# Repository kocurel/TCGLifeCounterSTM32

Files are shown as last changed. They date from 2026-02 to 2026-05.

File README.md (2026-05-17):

# STATUS: **WIP**

## Project: [TCGLifeCounterSTM32]
> Based on the predecessor: **TCGLifeCounterESP32**

## Project Overview
An advanced life counter for Trading Card Games (TCG), serving as an evolution of the TCG Life Counter model. The main focus is on mechanical and electronic optimization, specifically targeting miniaturization (component height limit H < 3mm) and UI tactile improvements.

## Versioning
- **v0.0.5**: Power delivery changes, schematic cleanup, LCD pin labeling, switching to a 100-pin STM32
- **v0.0.4**: Minor fix
- **v0.0.3**: MCU power delivery circuit
- **v0.0.2**: Backlight power circuit
- **v0.0.1**: Initial Draft

## Hardware Architecture & Design Decisions

### 1. Power Management (Backlight)
LCD backlight power delivery is based on the **AP3012** step-up converter in a **Constant Current** configuration:
- **Current Stabilization**: Implemented Low-Side Sensing with an **82 Ohm** sense resistor, forcing a stable **15.24 mA** current for the LEDs.
- **Brightness Control**: Managed via the **SHDN** pin using a PWM signal.

### 2. UI & Mechanicals
- **Tactile Switches**: Switched to **Omron B3F-4050** (130gf) to reduce noise and improve actuation ergonomics.
- **Stack-up**: Maximum component height under the display is **1.5 mm**, ensuring a safe clearance margin within the 3 mm profile.

## Project Structure
- `/hardware` - KiCad 9.0 project files (Schematics, PCB, Libraries).
- `/docs` - Technical documentation and comparative analyses:
    - `backlight_analysis.txt` - Detailed analysis of the FB loop and capacitor selection.
    - `switch_analysis.txt` - Comparison of switch acoustic parameters.
- `/firmware` - MCU source code (C/C++).

## Getting Started
### Prerequisites
- **KiCad 9.0+** (Required to open the latest `.kicad_pro` files).

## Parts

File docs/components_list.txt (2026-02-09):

https://www.tme.eu/pl/details/smd0805-82r-1%25/rezystory-smd/royalohm/0805s8f820jt5e/
https://www.tme.eu/pl/details/stm32h562rgt6/mikrokontrolery-st/stmicroelectronics/
https://www.tme.eu/en/details/ap3012ktr-e1/voltage-regulators-dc-dc-circuits/diodes-incorporated/
https://www.tme.eu/pl/details/vls3012cx-100m-1/dlawiki/tdk/
https://www.tme.eu/en/details/dt024dtft/tft-displays/displaytech/
https://www.tme.eu/en/details/cl21b105kbfnnne/mlcc-smd-capacitors/samsung/
https://www.tme.eu/pl/en/details/zl322-2x7p/pin-headers/connfly/ds1031-08-2-7p8bs41-3a/
https://www.tme.eu/en/details/usb4105-gf-a-120/usb-ieee1394-connectors/gct/
https://www.tme.eu/pl/details/esda25sc6y/diody-tvs-smd-jednokierunkowe/stmicroelectronics/
https://www.tme.eu/pl/details/cl10a106kp8nnnc/kondensatory-mlcc-smd/samsung/
https://www.tme.eu/pl/details/mcp73831t-2ati_ot/kontrolery-baterii-i-akumulatorow-uklady/microchip-technology/
https://www.tme.eu/pl/details/plp2-375/swiatlowody-do-led/bivar/
https://www.tme.eu/pl/details/ltst-c191krkt/diody-led-smd-kolorowe/liteon/
https://www.tme.eu/pl/details/cl10a475kp8nnnc/kondensatory-mlcc-smd/samsung/
https://www.tme.eu/pl/details/ap2112k-3.3trg1/stabilizatory-napiecia-nieregulowane-ldo/diodes-incorporated/
https://www.tme.eu/pl/details/c0603c104k8rac/kondensatory-mlcc-smd/kemet/c0603c104k8ractu/
https://www.tme.eu/pl/details/cl10b105ko8nnnc/kondensatory-mlcc-smd/samsung/
https://www.tme.eu/pl/details/grm188z71c475ke21d/kondensatory-mlcc-smd/murata/
https://www.tme.eu/pl/details/cl21b106koqnnne/kondensatory-mlcc-smd/samsung/
https://www.tme.eu/pl/details/grm188r61e106ka73d/kondensatory-mlcc-smd/murata/
https://www.tme.eu/pl/details/06033d104kat2a/kondensatory-mlcc-smd/kyocera-avx/
https://www.tme.eu/pl/en/details/ao3401a/smd-p-channel-transistors/alpha-omega-semiconductor/

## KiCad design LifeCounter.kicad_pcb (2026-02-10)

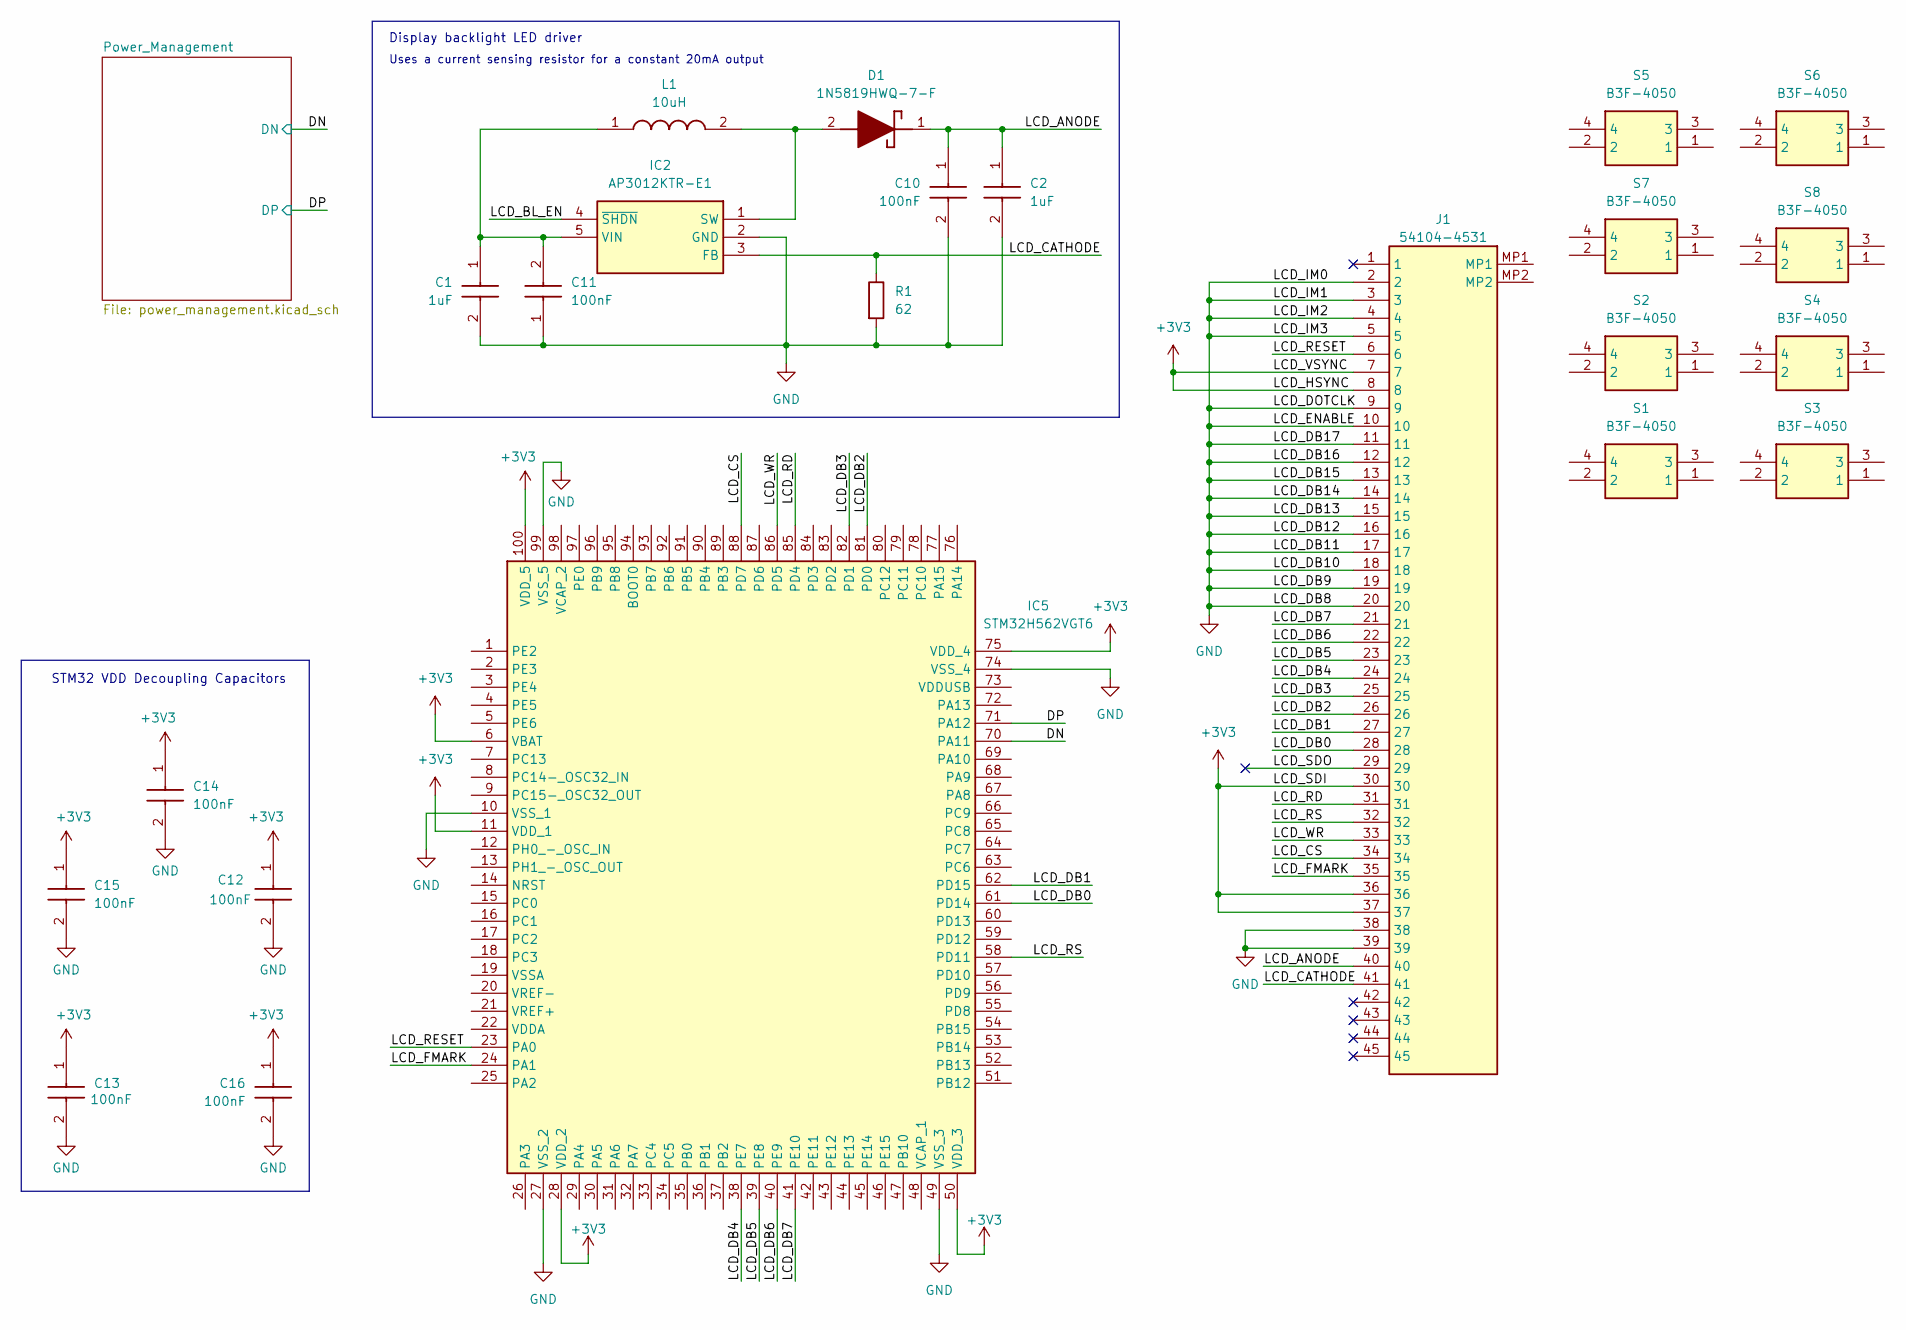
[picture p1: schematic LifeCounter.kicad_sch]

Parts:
C1: 1uF; Samsung_CAPC1608X90M; Manufacturer_Part_Number CL10B105KO8NNNC
C2: 1uF; Samsung_CAPC2012X135M; Manufacturer_Part_Number CL21B105KBFNNNE
C10: 100nF; Samsung_CAPC1608X90M; Manufacturer_Part_Number CL10B104KB8NNNC
C11, C12, C13, C14, C15, C16: 100nF; Kyocera_CAPC1608X90M; Manufacturer_Part_Number 06033D104KAT2A
D1: 1N5819HWQ-7-F; Diodes-Inc_SOD3716X145M; Manufacturer_Part_Number 1N5819HWQ-7-F
IC2: AP3012KTR-E1; Diodes-Inc_SOT95P282X145-5M; Manufacturer_Part_Number AP3012KTR-E1
IC5: STM32H562VGT6; STMicroelectronics_QFP50P1600X1600X160-100M; Manufacturer_Part_Number STM32H562VGT6
J1: 54104-4531; Molex_54104-4531; Mouser Part Number 538-54104-4531
L1: 10uH; TDK_VLS3012; Manufacturer_Part_Number VLS3012CX-100M-1
R1: 62; R_0805_2012Metric_Pad1.20x1.40mm_HandSolder
S1, S2, S3, S4, S5, S6, S7, S8: B3F-4050; Omron_B3F4050; Manufacturer_Part_Number B3F-4050

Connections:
+3V3: C12.1, C13.1, C14.1, C15.1, C16.1, IC5.6 (VBAT), IC5.11 (VDD_1), IC5.28 (VDD_2), IC5.50 (VDD_3), IC5.75 (VDD_4), IC5.100 (VDD_5), J1.7, J1.8, J1.30, J1.36, J1.37; also elsewhere on the board
/DN: IC5.70 (PA11); also elsewhere on the board
/DP: IC5.71 (PA12); also elsewhere on the board
/LCD_ANODE: C2.1, C10.1, D1.1 (K), J1.40
/LCD_BL_EN: IC2.4 (~SHDN)
/LCD_CATHODE: IC2.3 (FB), J1.41, R1.1
/LCD_CS: IC5.88 (PD7), J1.34
/LCD_DB0: IC5.61 (PD14), J1.28
/LCD_DB1: IC5.62 (PD15), J1.27
/LCD_DB2: IC5.81 (PD0), J1.26
/LCD_DB3: IC5.82 (PD1), J1.25
/LCD_DB4: IC5.38 (PE7), J1.24
/LCD_DB5: IC5.39 (PE8), J1.23
/LCD_DB6: IC5.40 (PE9), J1.22
/LCD_DB7: IC5.41 (PE10), J1.21
/LCD_FMARK: IC5.24 (PA1), J1.35
/LCD_RD: IC5.85 (PD4), J1.31
/LCD_RESET: IC5.23 (PA0), J1.6
/LCD_RS: IC5.58 (PD11), J1.32
/LCD_SDO: J1.29
/LCD_WR: IC5.86 (PD5), J1.33
GND: C1.2, C2.2, C10.2, C11.1, C12.2, C13.2, C14.2, C15.2, C16.2, IC2.2 (GND), IC5.10 (VSS_1), IC5.27 (VSS_2), IC5.49 (VSS_3), IC5.74 (VSS_4), IC5.99 (VSS_5), J1.2, J1.3, J1.4, J1.5, J1.9, J1.10, J1.11, J1.12, J1.13, J1.14, J1.15, J1.16, J1.17, J1.18, J1.19, J1.20, J1.38, J1.39, R1.2; also elsewhere on the board
unnamed: D1.2 (A), IC2.1 (SW), L1.2
unnamed: C1.1, C11.2, IC2.5 (VIN), L1.1

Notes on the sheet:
STM32 VDD Decoupling Capacitors
Uses a current sensing resistor for a constant 20mA output
Display backlight LED driver

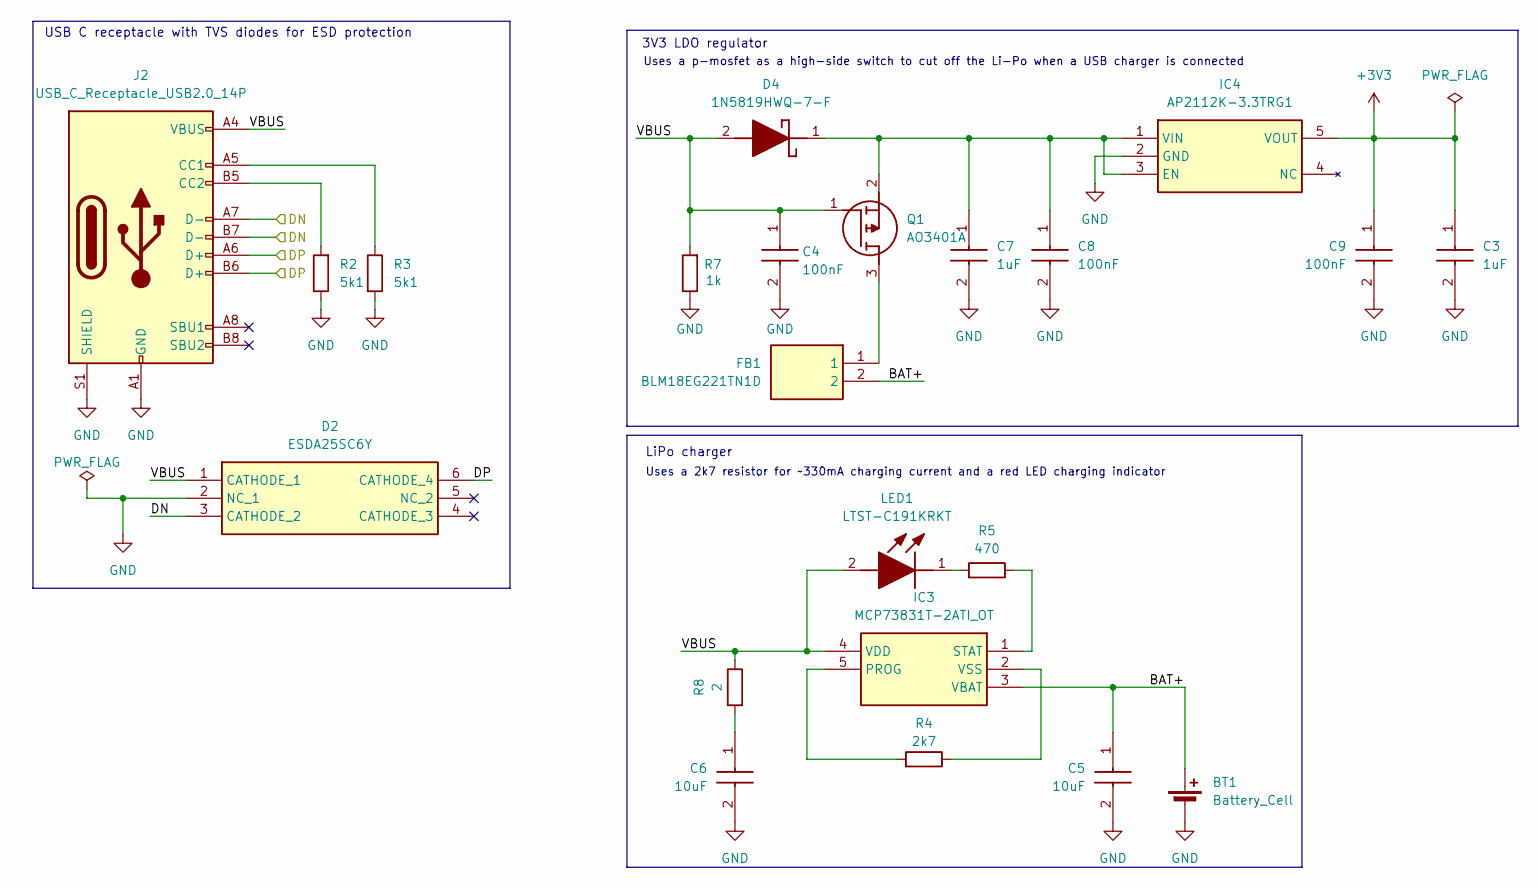
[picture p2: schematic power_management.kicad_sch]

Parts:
BT1: Battery_Cell
C3, C7: 1uF; Samsung_CAPC1608X90M; Manufacturer_Part_Number CL10B105KO8NNNC
C4, C8, C9: 100nF; Kemet_C0603; Manufacturer_Part_Number C0603C104K8RACTU
C5, C6: 10uF; Murata_GRM18x; Manufacturer_Part_Number GRM188R61E106KA73D
D2: ESDA25SC6Y; STMicroelectronics_SOT95P280X145-6M; Manufacturer_Part_Number ESDA25SC6Y
D4: 1N5819HWQ-7-F; Diodes-Inc_SOD3716X145M; Manufacturer_Part_Number 1N5819HWQ-7-F
FB1: BLM18EG221TN1D; Murata_BLM18EG101TH1D; Manufacturer_Part_Number BLM18EG221TN1D
IC3: MCP73831T-2ATI_OT; Microchip_SOT95P270X145-5M; Manufacturer_Part_Number MCP73831T-2ATI/OT
IC4: AP2112K-3.3TRG1; Diodes_Inc-SOT95P285X140-5M; Manufacturer_Part_Number AP2112K-3.3TRG1
J2: USB_C_Receptacle_USB2.0_14P; USB_C_Receptacle_GCT_USB4105-xx-A_16P_TopMnt_Horizontal
LED1: LTST-C191KRKT; Liteon_LEDC1608X55M; Manufacturer_Part_Number LTST-C191KRKT
Q1: AO3401A; Alpha&Omega_SOT95P280X125-3M; Manufacturer_Part_Number AO3401A
R2, R3: 5k1; R_0603_1608Metric_Pad0.98x0.95mm_HandSolder
R4: 2k7; R_0603_1608Metric_Pad0.98x0.95mm_HandSolder
R5: 470; R_0603_1608Metric_Pad0.98x0.95mm_HandSolder
R7: 1k; R_0603_1608Metric_Pad0.98x0.95mm_HandSolder
R8: 2; R_0603_1608Metric_Pad0.98x0.95mm_HandSolder

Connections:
+3V3: C3.1, C9.1, IC4.5 (VOUT); also elsewhere on the board
/DN: D2.3 (CATHODE_2), J2.A7 (D-), J2.B7 (D-); also elsewhere on the board
/DP: D2.6 (CATHODE_4), J2.A6 (D+), J2.B6 (D+); also elsewhere on the board
/Power_Management/BAT+: BT1.1 (+), C5.1, FB1.2, IC3.3 (VBAT)
/Power_Management/VBUS: C4.1, D2.1 (CATHODE_1), D4.2 (A), IC3.4 (VDD), J2.A4 (VBUS), J2.A9 (VBUS), J2.B4 (VBUS), J2.B9 (VBUS), LED1.2 (A), Q1.1 (G), R7.2, R8.1
GND: BT1.2 (-), C3.2, C4.2, C5.2, C6.2, C7.2, C8.2, C9.2, D2.2 (NC_1), IC4.2 (GND), J2.A1 (GND), J2.A12 (GND), J2.B1 (GND), J2.B12 (GND), J2.S1 (SHIELD), R2.1, R3.2, R7.1; also elsewhere on the board
unnamed: C6.1, R8.2
unnamed: C7.1, C8.1, D4.1 (K), IC4.1 (VIN), IC4.3 (EN), Q1.2 (S)
unnamed: IC3.5 (PROG), R4.2
unnamed: IC3.1 (STAT), R5.1
unnamed: IC3.2 (VSS), R4.1
unnamed: J2.A5 (CC1), R3.1
unnamed: J2.B5 (CC2), R2.2
unnamed: LED1.1 (K), R5.2
unnamed: FB1.1, Q1.3 (D)

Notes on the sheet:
Uses a 2k7 resistor for ~330mA charging current and a red LED charging indicator
3V3 LDO regulator
USB C receptacle with TVS diodes for ESD protection
Uses a p-mosfet as a high-side switch to cut off the Li-Po when a USB charger is connected
LiPo charger

Board: 4 copper layers, 44 parts (21 on the bottom side), 33 nets, no tracks yet.

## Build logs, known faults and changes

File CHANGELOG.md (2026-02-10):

# Changelog

## [0.0.6] - 2026-02-10
### Fixed
- Changed the orienation of AO3401A transistor by swapping Source and Drain to prevent 
backfeeding the USB voltage into the battery through the mosfet's body diode.
### Added
- Murata BLM18EG221TN1D Ferride bead in series with the Li-Po to protect from EMI backfeeding.
- a 100nF capacitor on the input line of AP2112K-3.3TRG1
### Changed
- Changed the value of the pmos pull-down resistor from 100k to 1k. 
- Removed the in-series 1k resistor on the pmos gate.

## [0.0.5] - 2026-02-09
### Added 
- Kyocera AVX 06033D104KAT2A capacitor library.
- Murata GRM188R61E106KA73D capacitor library.
- Samsung CL21B106KOQNNNE capacitor library.
- Murata GRM188Z71C475KE21D capacitor library.
- Samsung CL10B104KB8NNNC capacitor library.
- Samsung CL10B105KO8NNNC capacitor library.
- Alpha&Omega AO3401A p-mosfet library.
#### STM32
- Added a 100nF capacitor at every Vdd pin.
#### LCD connector
- Labeled the pins

#### Changed
- Switched STM32H562 to a 100 pin package to have access to FMC.

### Fixed
#### USB-C receptacle
- Removed the 10uF capacitor to prevent LC voltage spikes.
#### Li-Po charger
- Changed the capacitors of MCP73831T-2ATI_OT to match the schematic (increased the capacitance to 10uF).
- Added a 2 ohm resistor in series with the 10uF input capacitor.
#### 3V3 LDO
- Switched the Schottky diode from Bat+ to a high-side p-mosfet switch circuit

### Improved
#### Display backlight boost converter
- Changed the two 1uF capacitors from AP3012KTR-E1's output line to a 1uF 100nF pair.
- Added a 100nF capacitor on the input line
#### Kicad schematic
- Divided the schematic into two sheets for increased readability
- Marked and annotated distinct parts of the circuit

## [0.0.4] - 2026-02-08
### Fixed
- Added missing GND on AP3012KTR-E1.

## [0.0.3] - 2026-02-08
### Added
- USB C symbol on the schematic and 3D model.
- STMicroelectronics ESDA25SC6Y TVS diode library.
- Samsung CL10A106KP8NNNC capacitor library.
- Microchip MCP73831T Li-Po charger library.
- Liteon LTST-C191KRKT red charging indicator LED library.
- Samsung CL10A475KP8NNNC 4.7uF capacitor library.
- Diodes Incorporated AP2112K-3.3TRG1 LDO library.
- Kemet C0603C104K8RACTU 100nF capacitor library.
- Finished the mcu power delivery circuit.

## [0.0.2] - 2026-02-07

### Added
- Documented switch comparison analysis (docs/switch_analysis.txt).
- Omron B3F-4050 tactile switch library.
- Diodes Incorporated AP3012KTR-E1 step-up (boost) converter library.
- TDK VLS3012CX-100M-1 inductor library.
- Diodes Incorporated 1N5819HWQ-7-F Schottky rectifying diode library.
- Samsung CL21B105KBFNNNE capacitor library.
- Documented backlight power stage analysis (docs/backlight_analysis.txt).

### Technical Notes (Backlight Power Completed)
- Topology: Low-side current sensing using AP3012 FB pin (Vref=1.25V).
- Target Current: 15.24mA (via 82R/0603 1% Sense Resistor).
- Brightness Control: PWM dimming implemented via SHDN pin (recommended freq: 200Hz - 1kHz).
- Mechanical Clearance: All components selected for H < 1.5mm to fit within the 3mm stack-up limit under the LCD.

# END OF CHANGELOG

## [0.0.1] - 2026-02-07

### Added
- Initial project structure.
- Datasheets and libraries for the display, the FPC connector and STM microcontroller

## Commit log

2026-02-07 initial create
    [stm-prototype-v1.kicad_pcb, stm-prototype-v1.kicad_sch]
2026-02-07 renamed project and removed old files
    [life_counter.kicad_pcb, life_counter.kicad_sch]
2026-02-07 renamed project again
    [LifeCounter.kicad_sch, life_counter.kicad_pcb]
2026-02-07 added tact switch
2026-02-07 added step-uop converter and inductor for backlight's LED power
    [LifeCounter.kicad_pcb, LifeCounter.kicad_sch]
2026-02-07 imported the new footprints to footprints library
    [LifeCounter.kicad_sch]
2026-02-07 finished the power circuit for the LCD backlight
    [LifeCounter.kicad_pcb, LifeCounter.kicad_sch]
2026-02-08 bump version to v0.0.3, add USB C and TVS diode
    [LifeCounter.kicad_pcb, LifeCounter.kicad_sch]
2026-02-08 added a 10uF 0603 capacitor for usb c VBUS
    [LifeCounter.kicad_pcb, LifeCounter.kicad_sch]
2026-02-08 added lipo charger and red led indicator diode
    [LifeCounter.kicad_pcb, LifeCounter.kicad_sch]
2026-02-08 added 4.7uF capacitors for the lipo charger
    [LifeCounter.kicad_pcb, LifeCounter.kicad_sch]
2026-02-08 added LDO for 3v3 power delivery and a 100nF capacitor
    [LifeCounter.kicad_pcb, LifeCounter.kicad_sch]
2026-02-08 FIX: added missing GND on lcd backlight driver
    [LifeCounter.kicad_sch]
2026-02-09 capacitor changes
    [LifeCounter.kicad_pcb, LifeCounter.kicad_sch]
2026-02-09 divided schematic into two sheets
    [LifeCounter.kicad_sch, power_management.kicad_sch]
2026-02-09 cleaned up and annotated the schematic
    [LifeCounter.kicad_sch, power_management.kicad_sch]
2026-02-09 modified the LDO circuit by adding a p-mosfet high side switch
    [power_management.kicad_sch]
2026-02-09 labeled the FPC tape connector (LCD) pins
    [LifeCounter.kicad_sch, power_management.kicad_sch]
2026-02-09 labeled the LCD pins and switched over to a 100 pin stm32 package
    [LifeCounter.kicad_pcb, LifeCounter.kicad_sch]
2026-02-09 fix: added a 2ohm resistor to prevent voltage spikes on USB-C input (LC)
    [power_management.kicad_sch]
2026-02-10 fixed: changedthe orientation of the AO3401A mosfet
    [power_management.kicad_sch]
2026-02-10 added a ferride bead, added a 100nF filtering cap to the mosfet gate and changed the resistor pulldown value from 100k to 1k, removed the 1k resistor in series at the gate pin
    [LifeCounter.kicad_pcb, power_management.kicad_sch]
2026-04-17 Revise power management and UI details in README
    Updated power management and UI sections in README.
2026-04-17 Update brightness control description in README
    Removed frequency recommendation for PWM signal in brightness control section.
2026-04-23 Revise power management details in README
    Updated hardware architecture section with power management details.
